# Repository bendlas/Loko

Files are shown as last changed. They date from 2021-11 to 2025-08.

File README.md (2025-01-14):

# Loko
Tiny GPS tracker with LoraWAN
loco

This project is under development. It is currently in a stable state. Development is active and ongoing, but this is not yet a finished firmware. If you'd like to build one to help find bugs and design issues, please do!

Loko is the tiniest GPS tracker what works with Lora radio and can connect to LoraWAN, Loko is designed to track the important instrument / vehicles like drones, expensive quipments, farm equipments etc. 

Loko can run +30 days in a single charge. Loko weights only 12 grams which makes it very suitable to add small devices as well. 

I used ready to use lora-e5 module from Seeed (https://www.seeedstudio.com/LoRa-E5-Wireless-Module-p-4745.html). which as very simple to use AT comands to speed up the development process. It speed up the ton of coding work.

LOKO is avaliable to purchase from NOLILAB:  BUY LOKO (http://nolilab.com)

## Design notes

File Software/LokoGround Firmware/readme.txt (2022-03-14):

Loko ground unit use ESP32 module ,  its firmware written on micropython .  

first need to upload micropython package to ESP32 module by using Thonny IDE and the easily upload firmware and run

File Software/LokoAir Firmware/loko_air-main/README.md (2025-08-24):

# Hardware development / debugging

## Attach FT2232H as debugger

### Prerequisites

- An FT2232H Breakout Board
- An USB-C Breakout Board
- A 470Ω Resistor
- **OPTIONAL** A Breadboard

### Wiring

Attach wires, according to the [OpenOCD SWD Resistor Hack Schematic](https://github.com/openocd-org/openocd/blob/master/tcl/interface/ftdi/swd-resistor-hack.cfg) and the [Loko Air USB-C Pinout](https://raw.githubusercontent.com/tomipiriyev/Loko/refs/heads/main/Electronics/lokoAir/Loco%20Air.PDF)

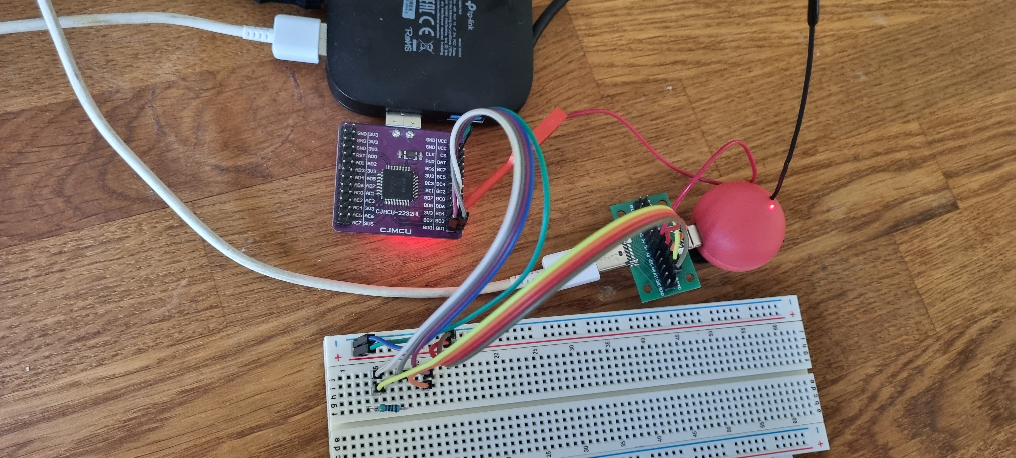
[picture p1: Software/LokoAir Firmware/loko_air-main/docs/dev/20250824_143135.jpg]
Overview
- 
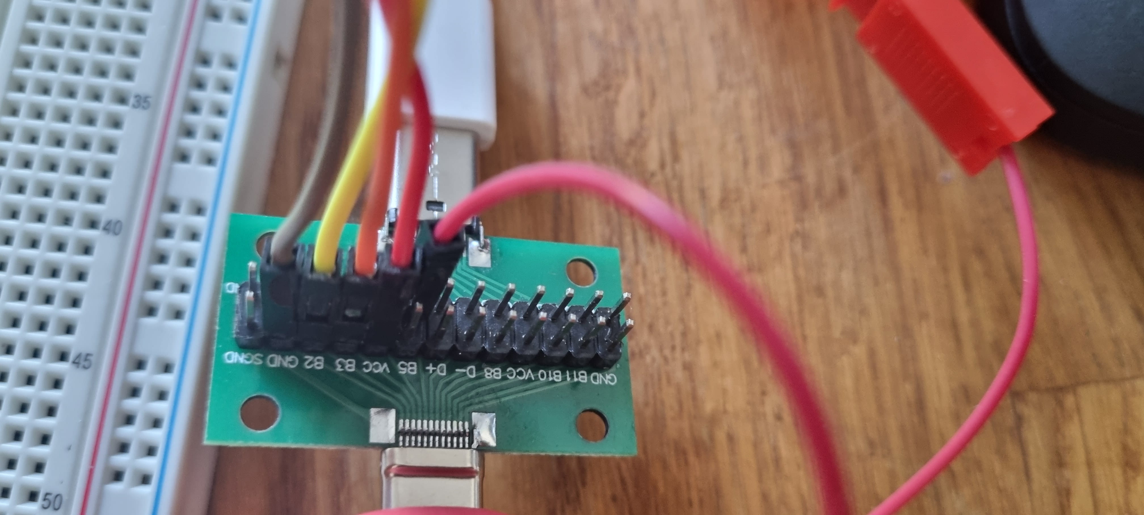
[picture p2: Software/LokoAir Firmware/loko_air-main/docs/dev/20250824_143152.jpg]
USB Breakout
- 
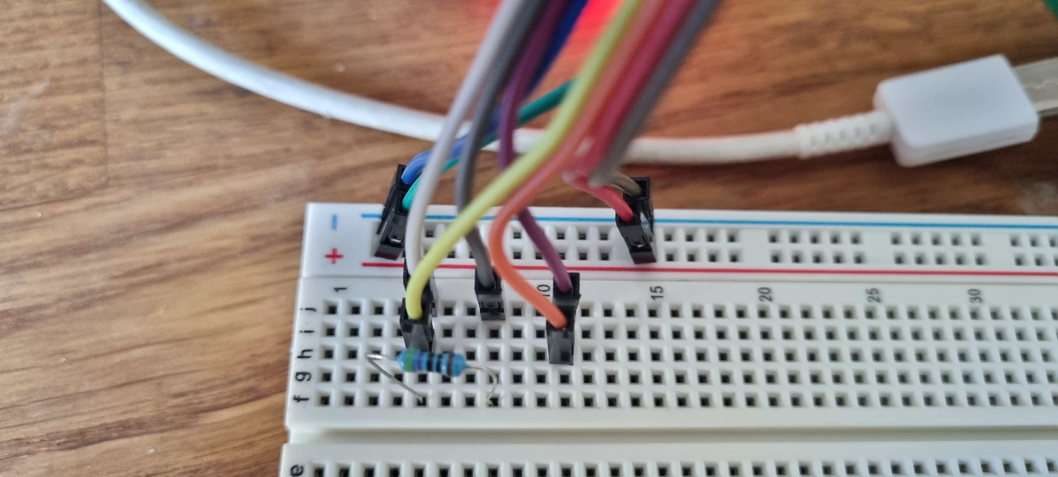
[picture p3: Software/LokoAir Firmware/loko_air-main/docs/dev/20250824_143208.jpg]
Breadboard
- 
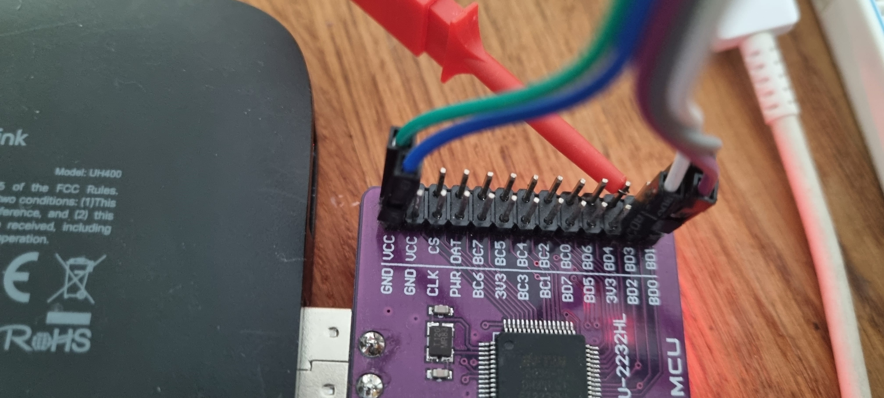
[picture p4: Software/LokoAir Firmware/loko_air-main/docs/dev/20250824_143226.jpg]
FT2232H 1
- 
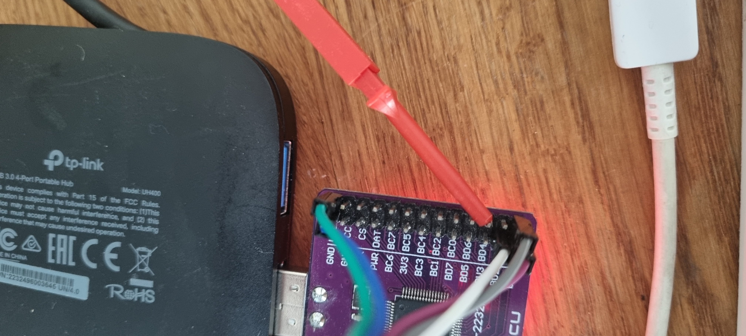
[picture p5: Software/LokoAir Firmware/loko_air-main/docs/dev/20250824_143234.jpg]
FT2232H 2
- 

### OpenOCD

```
openocd -f openocd-ft2232h.cfg -c init -c 'reset halt'
```

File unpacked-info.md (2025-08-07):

upstream: https://github.com/tomipiriyev/Loko.git
latest upstream commit: fe415ad25786e896874eeb3ae1ae623ab8c7d61a

# Unpack script

```sh
FILTER_BRANCH_SQUELCH_WARNING=1 git filter-branch -f --tree-filter '
  find . -name "*.zip" -execdir 7z -y x {} \; ; find . -name "*.zip" -exec rm {} \;
  find . -name "__MACOSX" -exec rm -r {} + ; find . -name ".DS_STORE" -exec rm -r {} +
' HEAD
```

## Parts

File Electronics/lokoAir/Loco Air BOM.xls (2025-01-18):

Designator | Footprint | Comment | Quantity | Manufacturer Part Number | https://lcsc.com/
C1, C4, C6, C17, C18, C7, C12 | CAPC1005X55N | 0.1uF | 7 | GRM155R71C104KA88D (https://octopart-clicks.com/click/altium?sku=490-3261-1-ND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) | C301930
C2, C3, C5, C8, C9, C31, C32, C11 | CAPC1005X55N | 10uF | 8 | CL05A106MP8NUB8 | C307415
D1, D2 | SOT65P210X110-3N | BAV99W | 2 | BAV99W | C26216
D3 | SOD-323 | 1N5819WS | 1 | 1N5819WS | C191023
GPS | PA1010D | PA1010D | 1 | PA1010D
LED1 | LEDC1608X80N_RED | 19-213/R6W-BP2Q2B/3T | 1 | 19-213/R6W-BP2Q2B/3T | C181863
Q1, Q2, Q5 | SOT65P210X110-3N | DMP2110UW-7 | 3 | DMP2110UW-7 | C3280217
Q3, Q4 | SOT65P210X110-3N | 2N7002W-7-F | 2 | 2N7002W-7-F | C139444
Q7 | SOP65P640X120-8N | FS8205A | 1 | FS8205A | C16052
R2 | RESC1005X40N | 2k | 1 | RC0402FR-072KL | C60488
R3, R5, R19, R21 | RESC1005X40N | 100K | 4 | RC0402FR-07100KL | C60491
R4, R10, R17, R18, R22, R23, R1 | RESC1005X40N | 10k | 7 | RC0402FR-0710KL | C60490
R7, R8, R9, R12, R13, R14, R29 | RESC1005X40N | 1k | 7 | RC0402FR-071KL | C106235
R16 | RESC1005X40N | 30K | 1 | RC0402FR-0730KL | C138008
R24, R25 | RESC1005X40N | 5.1K | 2 | RC0402FR-075K1L | C105872
R28 | RESC1005X40N | 100R | 1 | RC0402FR-07100RL | C106232
SW | TP12422673 | TP12422673 | 1 | TP12422673 | C5381384
U1 | SOT95P280X100-5N | MCP73832T-2DCI/OT | 1 | MCP73832T-2DCI/OT | C625601
U3 | MOUDLE28P-1.25-12X12X2.5MM | MOUDLE_LORA_E5 | 1
U5 | SOT95P280X145-6N | DW01A | 1 | DW01A | C351410
U8 | SOT95P280X100-5N | HE9073A30M5R | 1 | HE9073A30M5R | C723788
USB | MC-313F-14 | MC-313F-14 | 1 | MC-313F-14 | C428462
U2 | ESOP-10_L4.9-W3.9-P1.00-LS6.2-BL-EP | CH340K | 1 | CH340K | C968586
R6 | RESC1005X40N | 1M | 1 | RC0402FR-071ML | C138033

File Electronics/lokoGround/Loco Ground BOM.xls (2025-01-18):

Designator | Footprint | Comment | Quantity | Manufacturer Part Number | lcsc.com or link | JLC
LED1 | HL-AF-3528S39FU70GH203BC-A-S1-HL | HL-AF-3528S39FU70GH203BC-A-S1-HL | 1 | HL-AF-3528S39FU70GH203BC-A-S1-HL | C516144
BAT | EP-1619-1-NI | EP-1619-1-NI | 2 | EP-1619-1-NI
C1, C2, C6, C4, C7, C13, C5, C9, C11 | CAPC1608X100N | 10u | 9 | CL10A106KO8NQNC | C962136 | C19702
C12 | CAPC3216X100N | 100uF | 1 | GRM31CE70G107ME39L | C426649 | C15008
C14, C8, C10 | CAPC1608X100N | 0.1uF | 3 | CL10B104JB8NNNC | C24452 | C14663
CN1 | 0732511150 | SMA | 1 | 0732511150 | https://www.arrow.com/en/products/0732511150/molex
EN, IO0 | TSB008A2530A | TSB008A2530A | 2 | TSB008A2530A | C2888954 | C2888954
SW | TS-1094TS-B3D2-T-Y | TS-1094TS-B3D2-T-Y | 1 | TS-1094TS-B3D2-T-Y | C19077684 | C19077684
Q1 | SOT65P210X110-3N | PPMUT20V3 | 1 | PPMUT20V3 | C496543 | C496543
Q2, Q3, Q4, Q5 | SOT65P210X110-3N | 2N7002LT1G | 4 | 2N7002PW,115 | C255579 | C255579
R1, R2, R4, R5, R6, R7, R8, R9, R15, R16 | RESC1608X50N | 10k | 10 | RC0603FR-0710KL | C98220 | C98220
R10, R11, R17 | RESC1608X50N | 100k | 3 | RC0603FR-07100KL | C14675 | C14675
R12, R13, R14 | RESC1608X50N | 330R | 3 | RC0603FR-07330RL | C105881 | C105881
R3, R18, R19 | RESC1608X50N | 5.1k | 3 | RC0603FR-075K1L | C105580 | C105580
U1 | SOT95P280X100-5N | TLV75533PDBVR | 1 | TLV75533PDBVR | C404027 | C404027
U2 | ESP-WROOM-32 | ESP-WROOM-32 | 1 |  |  | C82899
U1 | SOT95P280X100-5N | MCP73832T-2DCI/OT | 1 | MCP73832T-2DCI/OT | C625601
U5 | SOP-16_150MIL | CH340B | 1 | CH340B | C81010 | C81010
U6 | MOUDLE28P-1.25-12X12X2.5MM | MOUDLE_LORA_E5 | 1
USB | USB-C_SMD-TYPE-C-31-M-12 | USB-C_SMD-TYPE-C-31-M-12 | 1 | TYPE-C-31-M-12 | C165948 | C165948
D1 | SOD80C | PMLL4148L,115 | 1 | PMLL4148L,115 | C78613 | C78613

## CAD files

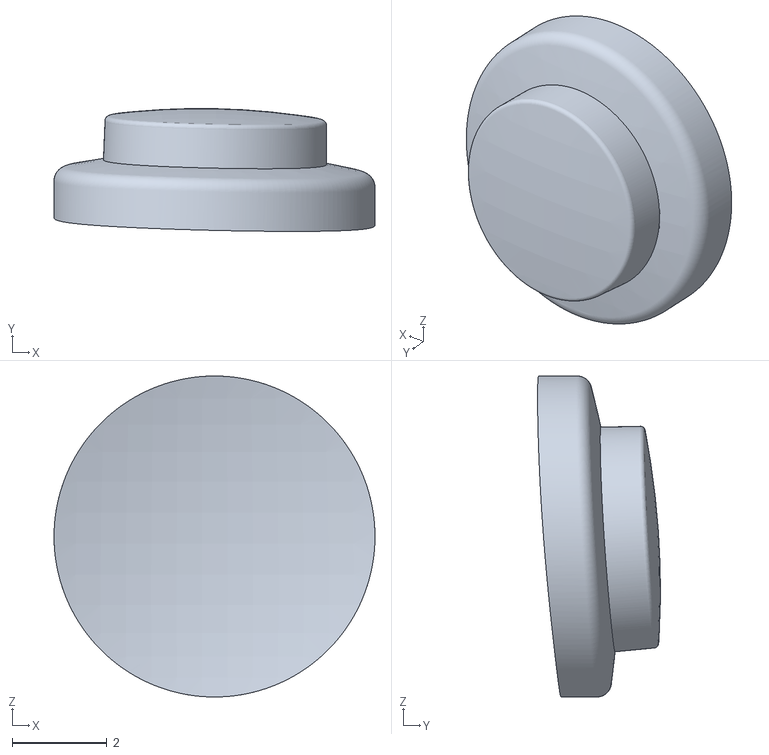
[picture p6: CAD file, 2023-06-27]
3D CAD/Loko Air/button - LA.stl
6.76 x 2.59 x 6.76

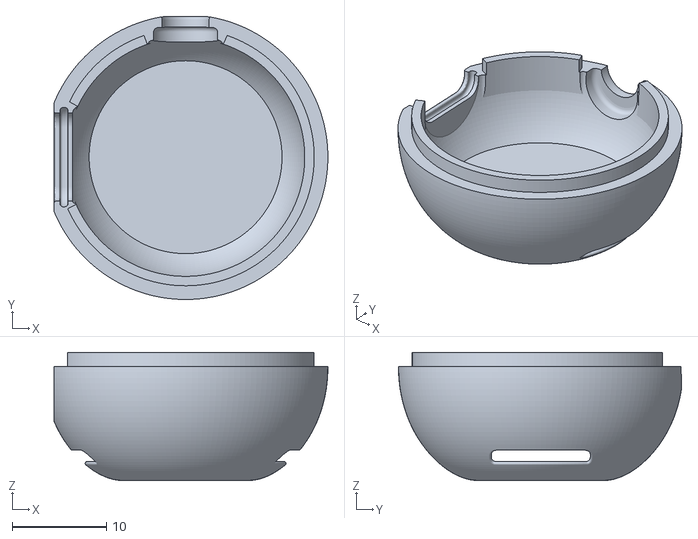
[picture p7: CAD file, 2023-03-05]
3D CAD/Loko Air/Loko-Air-Case/L-A-Buttom.stl
29.0 x 30.0 x 13.6

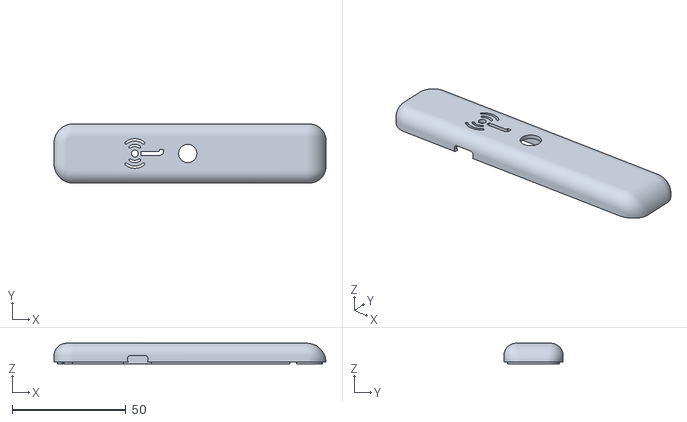
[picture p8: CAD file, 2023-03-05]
3D CAD/Loko Ground/L-G-CASE/L-G_TOP.stl
119.3 x 26.0 x 9.04

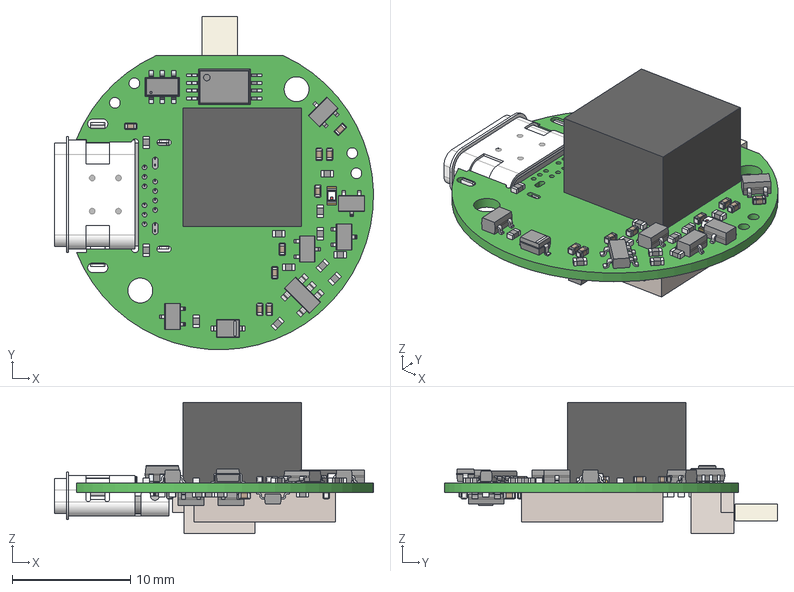
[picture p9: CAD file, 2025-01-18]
Electronics/lokoAir/Loco Air.step
26.9 x 28.1 x 11.1 mm
Board
RESC1005X40N x 24
SOT65P210X110-3N x 7
CAPC1005X55N x 15
SOT95P280X100-5N x 2
Extruded x 5
LEDC1608X80N_RED
PinsArrayLR x 2
SOD2713X115N
COMPOUND.step

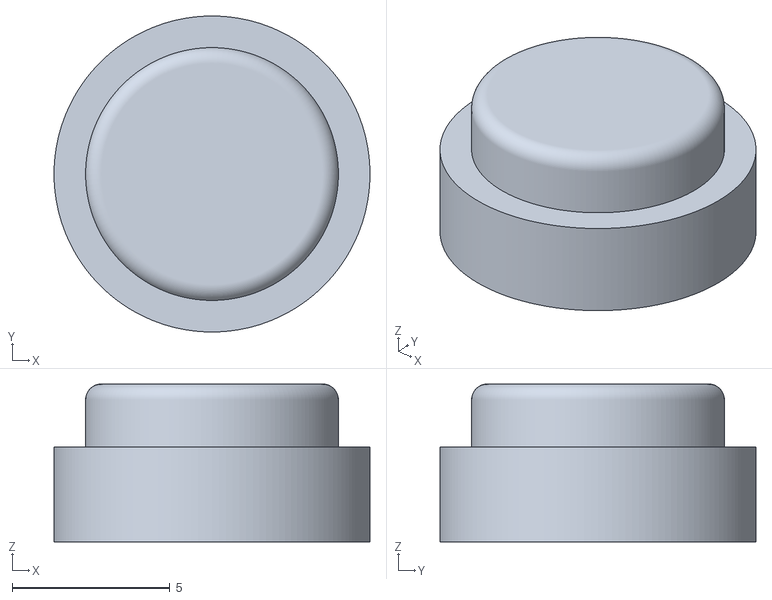
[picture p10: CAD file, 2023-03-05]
3D CAD/Loko Ground/L-G-CASE/L_G_button.stl
10.0 x 10.0 x 5.00

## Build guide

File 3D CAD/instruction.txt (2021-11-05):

Loko case is designed to be printed at SLA or SLS printers with high precision . 

it has 3 parts: upper case, lower case, and button. Highly recommended to print in SLS printer because SLA resin is not strong enough to hold the screws tight in place. 

Onshape link : https://cad.onshape.com/documents/ea37c157b53a530a6731bfff/w/7f627042196df546f38773f3/e/583637f66ec3a8c8bbab63be

Meanwhile you can use transparent plastic as Loko has built in LED,if you want it to be visable from outside.

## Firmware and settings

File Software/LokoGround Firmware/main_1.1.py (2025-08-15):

import machine
from machine import ADC
from machine import Pin, UART, Timer
from time import sleep_ms
from ucryptolib import aes
import ustruct as struct
import ubinascii
import ubluetooth
import json
import _thread
import sys
import gc

if 1:  # Must be 1 for real hardware
    VBAT_IN = ADC(Pin(39))
    BUTTON = Pin(35, Pin.IN)
    POWER_CTRL = Pin(12, Pin.OUT)
    LED_BLUE = Pin(21, Pin.OUT)
    LED_RED = Pin(18, Pin.OUT)
    LED_GREEN = Pin(19, Pin.OUT)
    LORA_UART = UART(2, 9600, timeout=100, txbuf=1024, rxbuf=1024)
else:
    # Loko debug board pinout
    VBAT_IN = ADC(Pin(1))
    BUTTON = Pin(0, Pin.IN)
    POWER_CTRL = Pin(12, Pin.OUT)
    LED_BLUE = Pin(47, Pin.OUT)
    LED_RED = Pin(36, Pin.OUT)
    LED_GREEN = Pin(37, Pin.OUT)
    LORA_UART = UART(2, 9600)

use_command_line_parser = True  # Set to True to enable command line interface

class SETTINGS():

    data = {
        'id2': 0,
        'freq': 868000000,  # Changed to Hz instead of MHz
        'p2p_key': "00" * 32,
    }

    def __init__(self, file_name='settings.json'):
        self.file_name = file_name
        self.load()

    def save(self):
        print('Save settings to {}:{}'.format(self.file_name, self.data))
        with open(self.file_name, "w") as fp:
            json.dump(self.data, fp)

    def load(self):
        try:
            with open(self.file_name, "r") as fp:
                self.data = json.load(fp)
                # Check if freq is stored in MHz and convert to Hz if needed
                if self.data['freq'] < 1000:
                    self.data['freq'] = self.data['freq'] * 1000000
                    self.save()
        except Exception as inst:
            print(inst)
            print("Settings file not found create new and use default settings")
            self.save()
        print('Load settings from {}:{}'.format(self.file_name, self.data))


class LOG_MANAGER():
    def __init__(self, max_entries=50, filename="lora_log.txt"):
        self.log = []
        self.max_entries = max_entries
        self.filename = filename
        self.file_mode = "a"  # append mode by default

        # Try to load existing logs from file
        try:
            self._load_from_file()
        except:
            print("No existing log file found or couldn't read it")

    def _load_from_file(self):
        try:
            with open(self.filename, "r") as f:
                lines = f.readlines()

            # Only keep the most recent entries if file is too large
            if len(lines) > self.max_entries:
                lines = lines[-self.max_entries:]

            # Parse the log entries
            for line in lines:
                if line.strip():  # Skip empty lines
                    try:
                        # Format: [TIMESTAMP] DATA
                        timestamp = line[1:line.find("]")]
                        data = line[line.find("]")+2:].strip()
                        self.log.append({
                            'timestamp': timestamp,
                            'data': data
                        })
                    except:
                        print(f"Couldn't parse log line: {line}")
        except:
            # Start with an empty log if file doesn't exist or can't be read
            self.log = []

    def add_entry(self, data):
        try:
            timestamp = machine.RTC().datetime()
            time_str = "{:04d}-{:02d}-{:02d} {:02d}:{:02d}:{:02d}".format(
                timestamp[0], timestamp[1], timestamp[2],
                timestamp[4], timestamp[5], timestamp[6]
            )
        except:
            # If RTC is not set, use a simple counter as timestamp
            time_str = "LOG-" + str(len(self.log) + 1)

        # Create a log entry with timestamp and data
        log_entry = {
            'timestamp': time_str,
            'data': data
        }

        # Manage the maximum length manually
        if len(self.log) >= self.max_entries:
            self.log.pop(0)  # Remove oldest entry

        self.log.append(log_entry)

        # Save to file
        try:
            with open(self.filename, self.file_mode) as f:
                f.write(f"[{time_str}] {data}\n")
            # Switch to append mode for future entries
            self.file_mode = "a"
        except:
            print("Failed to write log to file")

    def get_all_logs(self):
        return self.log

    def clear_logs(self):
        self.log = []
        # Overwrite the file with empty content
        try:
            with open(self.filename, "w") as f:
                f.write("")
            print("Log file cleared")
        except:
            print("Failed to clear log file")

    def export_logs(self):
        # Create a formatted string of all logs for export
        output = ""
        for entry in self.log:
            output += f"[{entry['timestamp']}] {entry['data']}\n"
        return output


class COMMAND_RECEIVER():

    def __init__(self, settings_obj, log_manager):
        self.exit_request = False
        self.settings = settings_obj
        self.log_manager = log_manager
        _thread.start_new_thread(self.receiver_thread, ())

    def set_handler(self, tag, number):
        # Modified to handle setting parameters with prefixed 'g'
        if tag == 'gid2':
            try:
                param = int(number)
                self.settings.data['id2'] = param
                self.settings.save()
                print('OK')
            except (ValueError, TypeError):
                print('Error: Expected numeric argument for gid2')

        elif tag == 'gfreq':
            try:
                param = int(number)
                if param < 100000000 or param > 1000000000:
                    print('Error: Invalid frequency, expected value in Hz between 100MHz and 1000MHz')
                    return
                self.settings.data['freq'] = param
                self.settings.save()
                print('OK')
            except (ValueError, TypeError):
                print('Error: Expected numeric argument for gfreq')

        elif tag == 'gp2p_key':
            # Validate that the key is a valid hex string of correct length
            if len(number) != 64 or not all(c in '0123456789abcdefABCDEF' for c in number):
                print('Error: Expected 64 character hexadecimal string for p2p_key')
                return
            self.settings.data['p2p_key'] = number
            self.settings.save()
            print('OK')
        else:
            print('Error: Unknown parameter')

    def get_info(self, *args):
        print('Settings:')
        print(f'  Device ID (id2): {self.settings.data["id2"]}')
        print(f'  Frequency: {self.settings.data["freq"]} Hz')
        print(f'  P2P Key: {self.settings.data["p2p_key"]}')
        print('OK')

    def print_help(self, *args):
        print('Available commands:')
        for cmd in self.commands:
            print('{} - {}'.format(cmd, self.commands[cmd]['info']))
        print('OK')

    def show_log(self, num_entries=None):
        logs = self.log_manager.get_all_logs()
        if not logs:
            print('Log is empty')
            print('OK')
            return

        if num_entries is not None:
            try:
                num = int(num_entries)
                logs = logs[-num:] if num < len(logs) else logs
            except ValueError:
                print('Error: Expected numeric argument for number of entries')
                return

        print('--- Log Entries ---')
        for i, entry in enumerate(logs):
            print(f'[{entry["timestamp"]}] {entry["data"]}')
        print('------------------')
        print('OK')

    def clear_log(self, *args):
        self.log_manager.clear_logs()
        print('Log cleared')
        print('OK')

    def show_mem(self, *args):
        # Show memory usage information
        gc.collect()
        free_mem = gc.mem_free()
        alloc_mem = gc.mem_alloc()
        total_mem = free_mem + alloc_mem

        print('Memory Usage:')
        print(f'  Free: {free_mem} bytes')
        print(f'  Used: {alloc_mem} bytes')
        print(f'  Total: {total_mem} bytes')
        print(f'  Percent used: {alloc_mem / total_mem * 100:.1f}%')
        print('OK')

    def save_log(self, *args):
        # Force saving of logs to file
        try:
            # Write all logs to file in overwrite mode
            with open(self.log_manager.filename, "w") as f:
                f.write(self.log_manager.export_logs())
            print(f"Logs saved to {self.log_manager.filename}")
            print('OK')
        except Exception as e:
            print(f"Error saving logs: {e}")
            print('Error: Failed to save logs')

    def exit_app(self, *args):
        # Save logs before exiting
        self.save_log()
        print('OK')
        self.exit_request = True
        sys.exit(1)

    commands = {
        'set': {'handler': set_handler, 'info': '\'set gid2 VALUE\' or \'set gfreq VALUE\' or \'set gp2p_key VALUE\''},
        'info': {'handler': get_info, 'info': 'print current settings'},
        'help': {'handler': print_help, 'info': 'show this text'},
        'log': {'handler': show_log, 'info': 'show log entries, optional: \'log NUMBER\' to show last N entries'},
        'clearlog': {'handler': clear_log, 'info': 'clear all log entries'},
        'savelog': {'handler': save_log, 'info': 'force save log entries to flash'},
        'mem': {'handler': show_mem, 'info': 'show memory usage statistics'},
        'exit': {'handler': exit_app, 'info': 'exit application'},
    }

    def receiver_thread(self):
        while True:
            try:
                rx_line = input("> ")
            except KeyboardInterrupt:
                print('Ctrl+C pressed')
                self.exit_app()

            if not rx_line:
                continue

            cmd_parts = rx_line.split()
            if not cmd_parts:
                continue

            cmd = cmd_parts[0]
            params = cmd_parts[1:] if len(cmd_parts) > 1 else []

            try:
                handler = self.commands[cmd]['handler']
            except KeyError:
                print('Error: Unknown command')
            else:
                handler(self, *params)


class LOKO_BLE():
    def __init__(self, name):
        # Create internal objects for the onboard LED_BLUE
        # blinking when no BLE device is connected
        # stable ON when connected
        self.led = LED_BLUE
        self.timer1 = Timer(0)
        self.name = name
        self.ble = ubluetooth.BLE()
        self.ble.active(True)
        self.disconnected()
        self.ble.irq(self.ble_irq)
        self.register()
        self.advertiser()
        self.ble.config(gap_name="Loko")
        self.is_connected = False

    def connected(self):
        self.is_connected = True
        self.led.value(0)
        self.timer1.deinit()
        print('Connected')

    def disconnected(self):
        self.is_connected = False
        self.timer1.init(period=300, mode=Timer.PERIODIC,
                         callback=lambda t: self.led.value(not self.led.value()))
        print('Disconnected')

    def ble_irq(self, event, data):
        if event == 1:  # _IRQ_CENTRAL_CONNECT:
            # A central has connected to this peripheral
            self.connected()
        elif event == 2:  # _IRQ_CENTRAL_DISCONNECT:
            # A central has disconnected from this peripheral.
            self.advertiser()
            self.disconnected()
        elif event == 3:  # _IRQ_GATTS_WRITE:
            # A client has written to this characteristic or descriptor.
            ble_msg = self.ble.gatts_read(self.rx).decode('UTF-8').strip()
            print('BLE Rx:', ble_msg)  # TODO: This message do not used

    def register(self):
        # Nordic UART Service (NUS)
        NUS_UUID = '6E400001-B5A3-F393-E0A9-E50E24DCCA9E'
        RX_UUID = '6E400002-B5A3-F393-E0A9-E50E24DCCA9E'
        TX_UUID = '6E400003-B5A3-F393-E0A9-E50E24DCCA9E'
        BLE_NUS = ubluetooth.UUID(NUS_UUID)
        BLE_RX = (ubluetooth.UUID(RX_UUID), ubluetooth.FLAG_WRITE)
        BLE_TX = (ubluetooth.UUID(TX_UUID), ubluetooth.FLAG_NOTIFY)
        BLE_UART = (BLE_NUS, (BLE_TX, BLE_RX,))
        SERVICES = (BLE_UART, )
        ((self.tx, self.rx,), ) = self.ble.gatts_register_services(SERVICES)

    def send(self, data):
        try:
            #self.ble.gatts_write(self.tx, data + '\n', True)
            self.ble.gatts_notify(0,self.tx, data + '\n')
            # self.ble.gatts_notify(0, self.tx, data + '\n') #doesn't work on ESP32S3, got OSError: -128, Remove it after tests on real hardware
        except Exception as inst:
            print('BLE Send error:', inst)

    def advertiser(self):
        name = bytes(self.name, 'UTF-8')
        adv_data = bytearray(b'\x02\x01\x02') + \
            bytearray((len(name) + 1, 0x09)) + name
        self.ble.gap_advertise(100, adv_data)
        print('ADV:', adv_data)


def battery_level():
    VBAT_IN.atten(ADC.ATTN_11DB)  # Adjust this based on your actual setup
    VBAT_IN.width(ADC.WIDTH_12BIT)  # Ensure this matches your earlier setting
    adc_reading = VBAT_IN.read()  # Get the ADC value
   # print(adc_reading)
    max_adc_value = 2455  # Max value for a 12-bit ADC
    max_battery_voltage = 2.1  # Adjust based on your battery's characteristics
    adc_battery_voltage = 2*(adc_reading * max_battery_voltage / max_adc_value)
    return adc_battery_voltage


def lora_set(freq_hz):
    # Convert Hz to MHz for LoRa module
    freq_mhz = freq_hz // 1000000

    LORA_UART.write("AT+MODE=TEST\r\n")
    sleep_ms(1000)
    print('Lora Resp:', LORA_UART.read())
    LORA_UART.write(
        "AT+TEST=RFCFG,{},SF12,125,12,15,14,ON,OFF,OFF\r\n".format(freq_mhz))
    sleep_ms(1000)
    print('Lora Resp:', LORA_UART.read())

def lora_data_receive():
    LORA_UART.write('AT+TEST=RXLRPKT\r\n')
    sleep_ms(500)
    print('Lora RX:', LORA_UART.read())

def is_hex_ascii_convertible(hex_string):
    if not all(c in '0123456789abcdefABCDEF' for c in hex_string):
        return False

    if len(hex_string) % 2 != 0:
        return False

    try:
        decoded_bytes = bytes(int(hex_string[i:i+2], 16) for i in range(0, len(hex_string), 2))
    except ValueError:
        return False

    return all(32 <= byte <= 126 for byte in decoded_bytes)

def parse_lora_module_message(message):
    # expected packet like: '+TEST: LEN:31, RSSI:-35, SNR:12\r\n+TEST: RX \"30302C3030302C35302E3531313732352C33302E3739313934352C33393936\"\r\n'
    line = str(message).split(" ")
    if len(line) > 2 and line[-2] == 'RX':
        received_data = line[-1][1:]
        end_hex_data_pos = received_data.find('\"')
        if end_hex_data_pos != -1:
            received_data = received_data[0:end_hex_data_pos]
            return received_data
    return None


def parse_loko_string_packet(string, key):
    values = string.split(',')
    print(values)
    if len(values) == 5:
        # message : '123,321,40.376123,49.850848,3420'
        id1 = int(values[0])
        id2 = int(values[1])

        # do not use float() result will round to five digit, ex: 50.511725 >>>> 50.51172 and 30.791945 >>>> 30.79195
        lat = (values[2])
        lon = (values[3])

        vbat = int(values[4])
        return {'id1': id1, 'id2': id2, 'lat': lat, 'lon': lon, 'vbat': vbat}
    if len(values) == 7:
        # message : '00,000,54.685349,25.282091,117,0,6432'
        id1 = int(values[0])
        id2 = int(values[1])

        # do not use float() result will round to five digit, ex: 50.511725 >>>> 50.51172 and 30.791945 >>>> 30.79195
        lat = (values[2])
        lon = (values[3])
        alt_meters = int(values[4])
        meters_per_second = int(values[5])

        vbat = int(values[6])
        return {'id1': id1, 'id2': id2, 'lat': lat, 'lon': lon, 'vbat': vbat, 'alt': alt_meters, 'mps': meters_per_second}
    if len(values) == 3:
        # message :'00,000,KsC72EMf5cAYJU8eATDTMg=='
        id1 = int(values[0])
        id2 = int(values[1])
        base64 = values[2]
        encrypted_bytes = ubinascii.a2b_base64(base64)

        # Initialize the AES cipher in ECB mode
        cipher = aes(key, 1)  # 1 for ECB mode
        decrypted_bytes = cipher.decrypt(encrypted_bytes)
        checksum = sum(decrypted_bytes[:-1]) % 256
        lat, lon, vbat_mv, alt_meters, speed_mps, reserved1, integrity= struct.unpack('<ffHHHBB', decrypted_bytes)
        if checksum == integrity:
            return {'id1': id1, 'id2': id2, 'lat': lat, 'lon': lon, 'vbat': vbat_mv, 'alt': alt_meters, 'mps': speed_mps}
        else:
            print('Can\'t decrypt, possible wrong key')

    return None

def bin_unpack_vbat(vbat):
    return (vbat + 27) * 0.1

def bin_unpack_lat_lon_24(packed_data):
    # Extract and convert 3 bytes for latitude to a signed 24-bit integer
    lat_lon_scaled = (packed_data[0] << 16) | (packed_data[1] << 8) | packed_data[2]
    if lat_lon_scaled & 0x800000:  # Check if the sign bit is set for a negative value
        lat_lon_scaled -= 0x1000000  # Convert to signed 24-bit integer

    scaling_factor = 10000.0
    lat_lon = lat_lon_scaled / scaling_factor

    return lat_lon

def bin_unpack_lat_lon_32(packed_data):
    # Extract and convert 4 bytes for latitude to a signed 32-bit integer
    lat_lon_scaled = (packed_data[0] << 24) | (packed_data[1] << 16) | (packed_data[2] << 8) | packed_data[3]
    if lat_lon_scaled & 0x80000000:  # Check if the sign bit is set for a negative value
        lat_lon_scaled -= 0x100000000  # Convert to signed 32-bit integer

    scaling_factor = 1000000.0
    lat_lon = lat_lon_scaled / scaling_factor

    return lat_lon

def parse_loko_bin_packet(bin_data, key):
    id1 = 0
    id2 = 0
    vbat_mv = 0
    packet_version = 0
    lat = 0.0
    lon = 0.0
    alt_meters = 0
    speed_mps = 0
    data = bytes(int(bin_data[i:i+2], 16) for i in range(0, len(bin_data), 2))
    if len(data) == 15:
        id1, id2, vb_version, lat_24bit, lon_24bit= struct.unpack("<IIB3s3s", data)
        packet_version = (vb_version >> 4) & 0x0F
        vbat_mv = bin_unpack_vbat(vb_version & 0x0F)
        lat = bin_unpack_lat_lon_24(lat_24bit)
        lon = bin_unpack_lat_lon_24(lon_24bit)
    if len(data) == 17:
        id1, id2, vb_version, lat_32bit, lon_32bit= struct.unpack("<IIB4s4s", data)
        packet_version = (vb_version >> 4) & 0x0F
        vbat_mv = bin_unpack_vbat(vb_version & 0x0F)
        lat = bin_unpack_lat_lon_32(lat_32bit)
        lon = bin_unpack_lat_lon_32(lon_32bit)
    elif len(data) == 18:
        id1, id2, vb_version, lat_24bit, lon_24bit, speed_mps, alt_meters= struct.unpack("<IIB3s3sBh", data)
        packet_version = (vb_version >> 4) & 0x0F
        vbat_mv = bin_unpack_vbat(vb_version & 0x0F)
        lat = bin_unpack_lat_lon_24(lat_24bit)
        lon = bin_unpack_lat_lon_24(lon_24bit)
    elif len(data) == 20:
        id1, id2, vb_version, lat_32bit, lon_32bit, speed_mps, alt_meters= struct.unpack("<IIB4s4sBh", data)
        packet_version = (vb_version >> 4) & 0x0F
        vbat_mv = bin_unpack_vbat(vb_version & 0x0F)
        lat = bin_unpack_lat_lon_32(lat_32bit)
        lon = bin_unpack_lat_lon_32(lon_32bit)
    elif len(data) == 25:
        id1, id2, vb_version, aes_payload= struct.unpack(">IIB16s", data)
        packet_version = (vb_version >> 4) & 0x0F
        encrypted_bytes = bytes(aes_payload)

        # Initialize the AES cipher in ECB mode
        cipher = aes(key, 1)  # 1 for ECB mode
        # cipher = AES.new(key, AES.MODE_ECB)
        decrypted_bytes = cipher.decrypt(encrypted_bytes)
        checksum = sum(decrypted_bytes[:-1]) % 256
        if vb_version == 2:
            (vb_version, lat_24bit, lon_24bit, speed_mps, alt_meters, reserved1,  integrity) = struct.unpack('<B3s3sBH5sB', decrypted_bytes)
            if checksum != integrity:
                print('Can\'t decrypt, possible wrong key')
            else:
                vbat_mv = bin_unpack_vbat(vb_version & 0x0F)
                lat = bin_unpack_lat_lon_24(lat_24bit)
                lon = bin_unpack_lat_lon_24(lon_24bit)
        elif vb_version == 5:
            (vb_version, lat_32bit, lon_32bit, speed_mps, alt_meters, reserved1,  integrity) = struct.unpack('<B4s4sBH3sB', decrypted_bytes)
            if checksum != integrity:
                print('Can\'t decrypt, possible wrong key')
            else:
                vbat_mv = bin_unpack_vbat(vb_version & 0x0F)
                lat = bin_unpack_lat_lon_32(lat_32bit)
                lon = bin_unpack_lat_lon_32(lon_32bit)

    return {'id1': id1, 'id2': id2, 'lat': lat, 'lon': lon, 'vbat': vbat_mv, 'alt': alt_meters, 'mps': speed_mps}

def button_timer(pin):
    print('Power value:', POWER_CTRL.value())
    if BUTTON.value() == 0:
        print("counting till 3")
        sleep_ms(2000)
        if BUTTON.value() == 0:
            LED_RED.value(not LED_GREEN.value())
            POWER_CTRL.value(not POWER_CTRL.value())
            print('Power value:', POWER_CTRL.value())
        else:
            print('Button released')
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

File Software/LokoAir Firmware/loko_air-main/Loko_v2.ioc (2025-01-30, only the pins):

Mcu.UserName=STM32WLE5JCIx
PA0.GPIO_Label=BUTTON
PA0.Signal=PWR_WKUP1
PA10.GPIO_Label=CHARGER_STAT
PA10.Signal=GPXTI10
PA13.Signal=DEBUG_JTMS-SWDIO
PA14.Signal=DEBUG_JTCK-SWCLK
PA15.GPIO_Label=TIME_PULSE
PA15.Signal=GPXTI15
PA2.GPIO_Label=GNSS_WAKEUP
PA2.Signal=GPIO_Output
PA3.GPIO_Label=__UNUSED1
PA3.Signal=GPIO_Input
PA9.GPIO_Label=GNSS_EN
PA9.Signal=GPIO_Output
PB10.GPIO_Label=LED
PB10.Signal=GPIO_Output
PB13.GPIO_Label=VBAT_MEASURE
PB13.Signal=ADC_IN0
PB14.GPIO_Label=__UNUSED6
PB14.Signal=GPIO_Input
PB15.GPIO_Label=VBAT_MEASURE_EN
PB15.Signal=GPIO_Output
PB3.GPIO_Label=__UNUSED3
PB3.Signal=GPIO_Input
PB4.GPIO_Label=__UNUSED5
PB4.Signal=GPIO_Input
PB5.GPIO_Label=__UNUSED2
PB5.Signal=GPIO_Input
PB6.GPIO_Label=USB_TXD
PB6.Signal=USART1_TX
PB7.GPIO_Label=USB_RXD
PB7.Signal=USART1_RX
PB9.GPIO_Label=__UNUSED4
PB9.Signal=GPIO_Input
PC0.GPIO_Label=GPS_RX
PC0.Signal=LPUART1_RX
PC1.GPIO_Label=GPS_TX
PC1.Signal=LPUART1_TX
PC14-OSC32_IN.Signal=RCC_OSC32_IN
PC15-OSC32_OUT.Signal=RCC_OSC32_OUT

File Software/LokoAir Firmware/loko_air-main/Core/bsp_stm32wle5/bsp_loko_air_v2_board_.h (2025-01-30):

#pragma once

#ifdef __cplusplus
extern "C" {
#endif

/*GPIO A*/

#define BUTTON_PIN             LL_GPIO_PIN_0
#define BUTTON_GPIO_PORT       GPIOA
#define BUTTON_PULL_SETTINGS   LL_GPIO_PULL_NO
#define BUTTON_ACTIVE_LEVEL    GPIO_PIN_SET
#define GNSS_WAKEUP_PIN        LL_GPIO_PIN_2
#define GNSS_WAKEUP_GPIO_PORT  GPIOA
#define GNSS_EN_PIN            LL_GPIO_PIN_9
#define GNSS_EN_GPIO_PORT      GPIOA
#define CHARGER_STAT_PIN       LL_GPIO_PIN_10
#define CHARGER_STAT_GPIO_PORT GPIOA
#define TIME_PULSE_PIN         LL_GPIO_PIN_15
#define TIME_PULSE_GPIO_PORT   GPIOA

/*GPIO B*/

#define V_USB_DETECT_PIN          LL_GPIO_PIN_3
#define V_USB_DETECT_GPIO_PORT    GPIOB
#define USB_TXD_PIN               LL_GPIO_PIN_6
#define USB_TXD_GPIO_PORT         GPIOB
#define USB_RXD_PIN               LL_GPIO_PIN_7
#define USB_RXD_GPIO_PORT         GPIOB
#define LED_PIN                   LL_GPIO_PIN_10
#define LED_GPIO_PORT             GPIOB
#define VBAT_MEASURE_PIN          LL_GPIO_PIN_13
#define VBAT_MEASURE_GPIO_PORT    GPIOB
#define VBAT_MEASURE_EN_PIN       LL_GPIO_PIN_15
#define VBAT_MEASURE_EN_GPIO_PORT GPIOB

/*GPIO C*/

#define GPS_RX_PIN       LL_GPIO_PIN_0
#define GPS_RX_GPIO_PORT GPIOC
#define GPS_TX_PIN       LL_GPIO_PIN_1
#define GPS_TX_GPIO_PORT GPIOC

#ifdef __cplusplus
}
#endif

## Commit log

2021-11-04 Create 3D CAD
2022-03-14 Loko ground unit micro python firmware
2022-04-03 stm32 firmware
2023-03-05 LOKO Ground case STL files
    [L-G_TOP.stl, L_G_button.stl]
2023-03-05 Loko Air case with strip
    [L-A-Buttom.stl]
2023-03-11 Updated Germber
    [Loco Ground.GBL, Loco Ground.GBO, Loco Ground.GBP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]
2023-03-11 Updated BOM , added a Diod
    [Loco Ground BOM.xls]
2023-03-29 Real battery capacity test
2023-03-29 Battery Capacity test result
    [CP1654 VARTA battery Capacity test.xlsx]
2023-06-20 Air BOM
    [Loco Air BOM.xls]
2023-06-27 pnp file
    [Pick Place for Loco Air.csv]
2023-12-10 Loko Receiver firmware
    need Thonny IDE to upload the firmware to ESP32 inside the Ground unit
2025-01-18 Loko Air electronic files
    [Loco Air BOM.xls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]
2025-01-18 Loko Air files
    [Loco Air BOM.xls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]
2025-01-18 Loko Ground electronics
    [Loco Ground BOM.xls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]
2025-01-18 Loko Ground firmware
    micropython code
2025-01-30 firmware 1.71
    [Loko_v2 Release.cfg, loko-air-trace-example.csv, loko-config-requirements.txt]
2025-07-19 1.73 firmware
    [Loko_v2 Release.cfg, loko-air-trace-example.csv, loko-config-requirements.txt]
2025-08-15 fix ground station lora config
    as per https://github.com/tomipiriyev/Loko/issues/19
    [main_1.1.py]
